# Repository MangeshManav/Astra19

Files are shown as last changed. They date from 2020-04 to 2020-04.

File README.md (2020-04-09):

# Astra19
Face Shields For Frontliners
* 
Face shield provides protection of the facial area and associated mucous membranes (eyes,
nose, mouth) from splashes, sprays and spatter of body fluids.

A Face Shield is attached to the head with the help of a headband and an elastic strap. The
headband is made from MDF sheets. A transparent clear polyester sheet is used as a shield that
protects the face from any airborne fluid particles. This is secured to the headband as shown in
the photos. Used shields can be removed and replaced with new shields very easily.

During this pandemic of COVID-19, there is an immense shortage of Face shields in the market
which is a must have accessory for our frontline warriors including Police & Healthcare
professionals who are exposed to the COVID positive patients day-in and day-out. Due to their
acute shortage, prices have shot up, exposing these frontline warriors at severe risk.

The Face Shield Project is a collaborative effort by Venture Center Team and group of startup entrepreneurs to design, fabricate and deliver faceshields to the frontline workers.

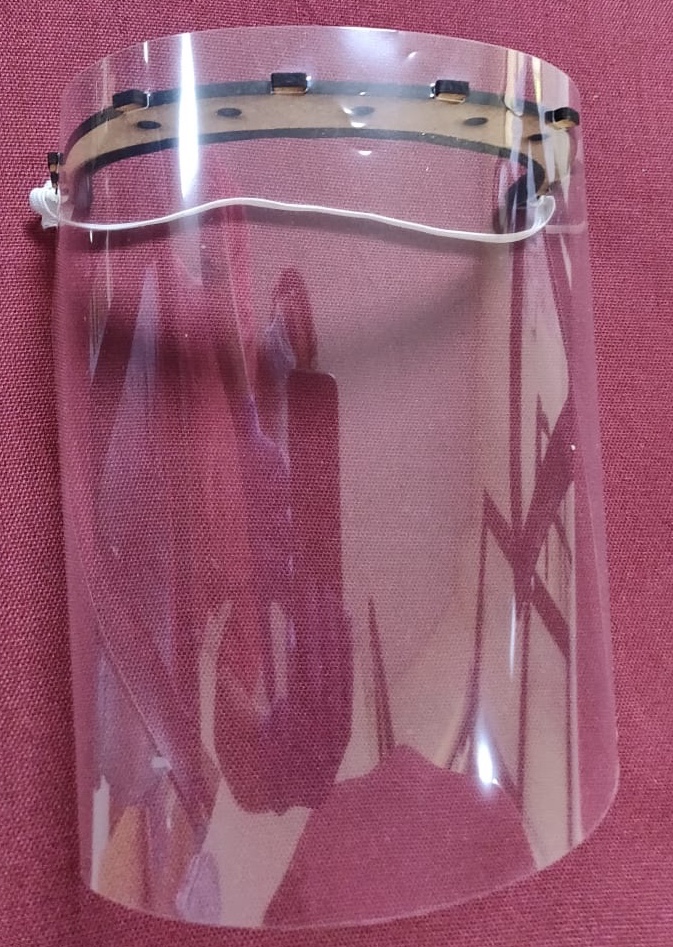
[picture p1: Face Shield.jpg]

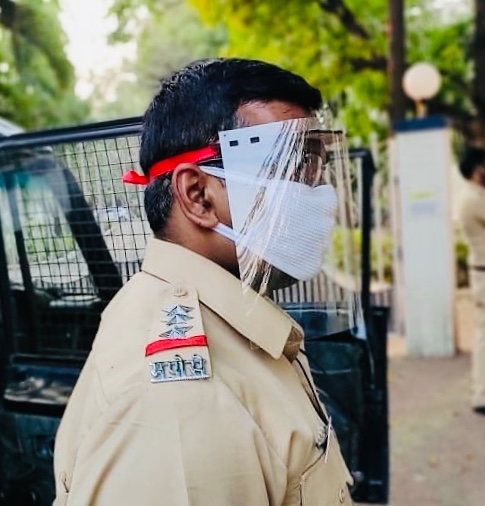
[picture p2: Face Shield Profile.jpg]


Shield: [][cc-by-sa]

This work is licensed under a [Creative Commons Attribution-ShareAlike 4.0
International License][cc-by-sa].

[][cc-by-sa]

[cc-by-sa]: http://creativecommons.org/licenses/by-sa/4.0/
[cc-by-sa-image]: https://licensebuttons.net/l/by-sa/4.0/88x31.png
[cc-by-sa-shield]: https://img.shields.io/badge/License-CC%20BY--SA%204.0-lightgrey.svg

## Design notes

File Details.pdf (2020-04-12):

### Venture Center Startups against COVID-19 Face Shield

Raw Materials
| Material Name | Specifications | Cost for bulk (Rs) | Price per piece (Rs) | Qty required per piece | Source
1 Plastic Sheet or OHP | Sheets | A4, 100 microns + | 190/ packet of 100 pieces | 1.9-2.5 | 1 | Stationary Shop
2 | Headband | MDF Sheet (8*4 sq ft, 3.5 mm) | 320/ Sheet | 1.6 - 3 | 10*15 cm | Plywood Store
3 | Elastic Band | 4-6 mm, | 5/ meter | 1.66 - 3 | 30 cm | Textile/Tailoring Shop
4 | Laser Cutter | Holder and Plastic Sheet cut into shape | 20/Sq Ft | 5 - 10 | 1-2 mins | Wood working/Graphics Store
5 | Miscellaneous Costs | Gloves, Sanitizer, Packaging Bags, Sandpaper, Cleaning Clothes, Tranportation | NA | 6 - 10 | | NA

Design files: https://github.com/MangeshManav/Astra19 or https://tinyurl.com/fspune

Face Shield Details: http://www.protoshop.in/covid19-faceshields/

Contact:

1. 9975571504 (Aditya Kabra)
2. 7798626714 (Mitesh Rasal)

Credits: Inspired from Maker’s Asylum Mumbai

Protected by Creative Commons License:

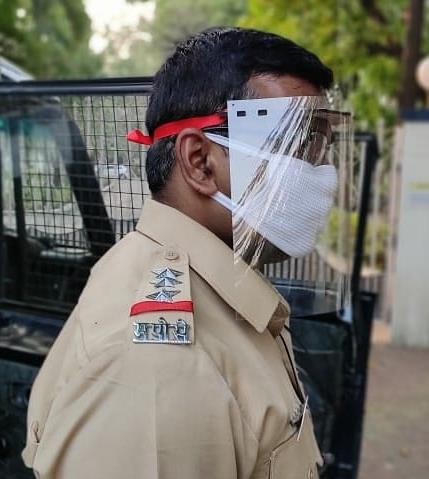
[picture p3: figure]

Subject to the terms and conditions of this Public License, the Licensor hereby grants You a worldwide, royalty-free, non-sub-licensable, non-exclusive, irrevocable license to exercise the Licensed Rights in the Licensed Material to: reproduce and Share the Licensed Material, in whole or in part, for Non-commercial purposes only; and produce, reproduce, and Share Adapted Material for Non-commercial purposes only.

### Face Shield

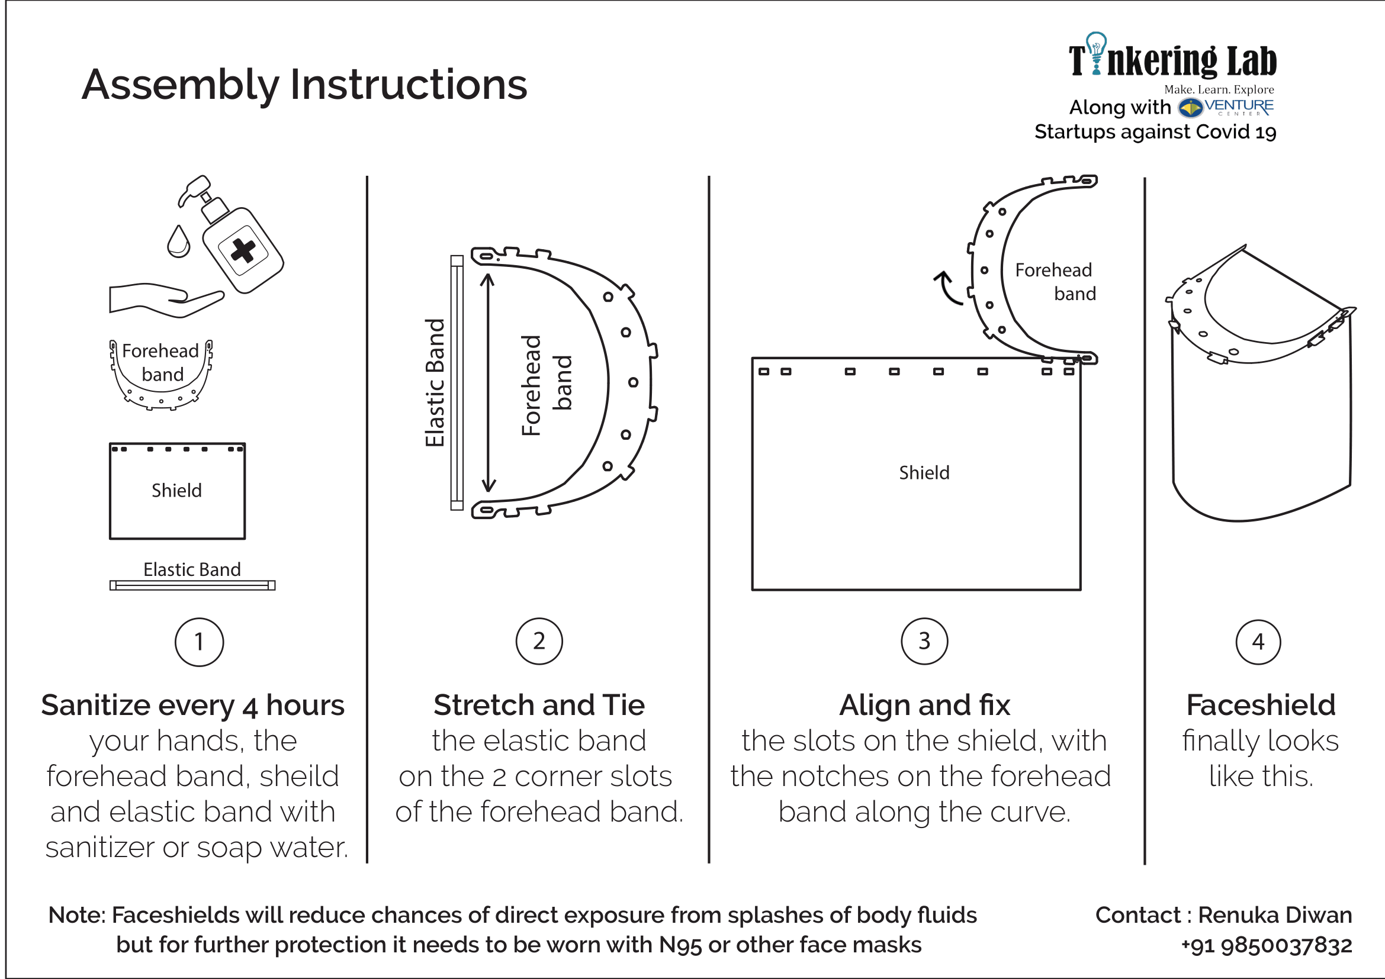
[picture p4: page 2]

### Face Shield

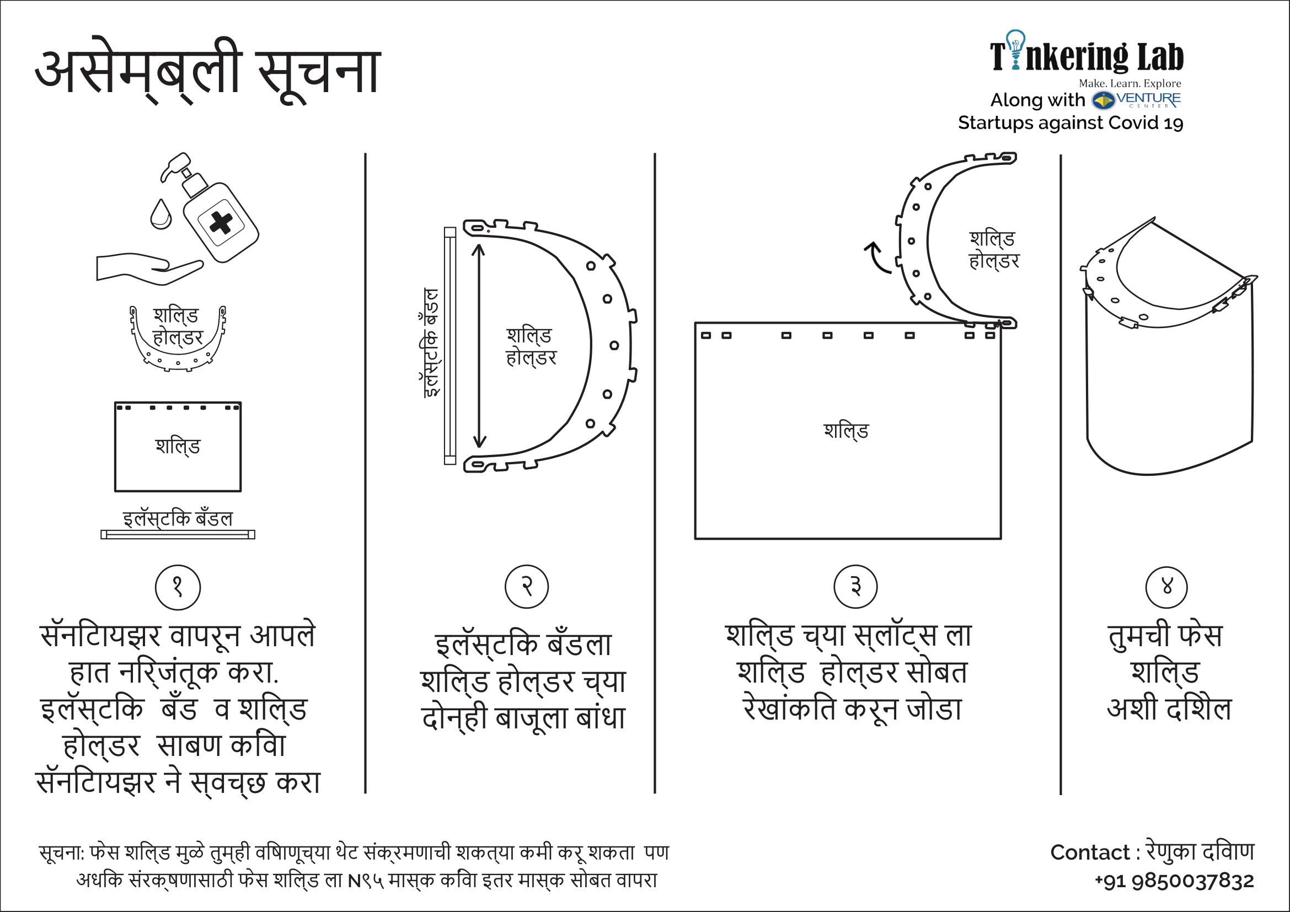
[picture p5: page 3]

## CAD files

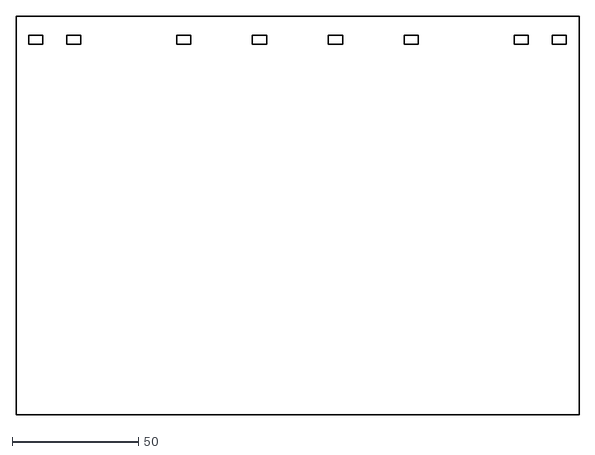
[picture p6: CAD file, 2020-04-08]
Plastic Sheet.dxf
222.8 x 157.5

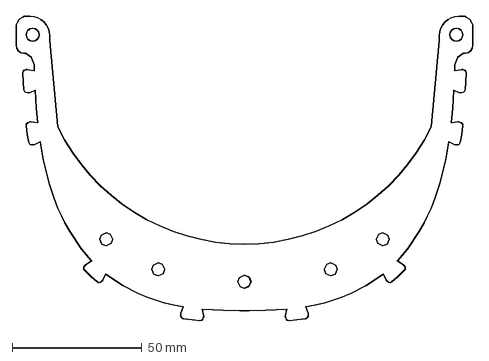
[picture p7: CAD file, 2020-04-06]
Headband.DXF
175.7 x 117.2 mm

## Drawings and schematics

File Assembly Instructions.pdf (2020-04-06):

## Assembly Instructions

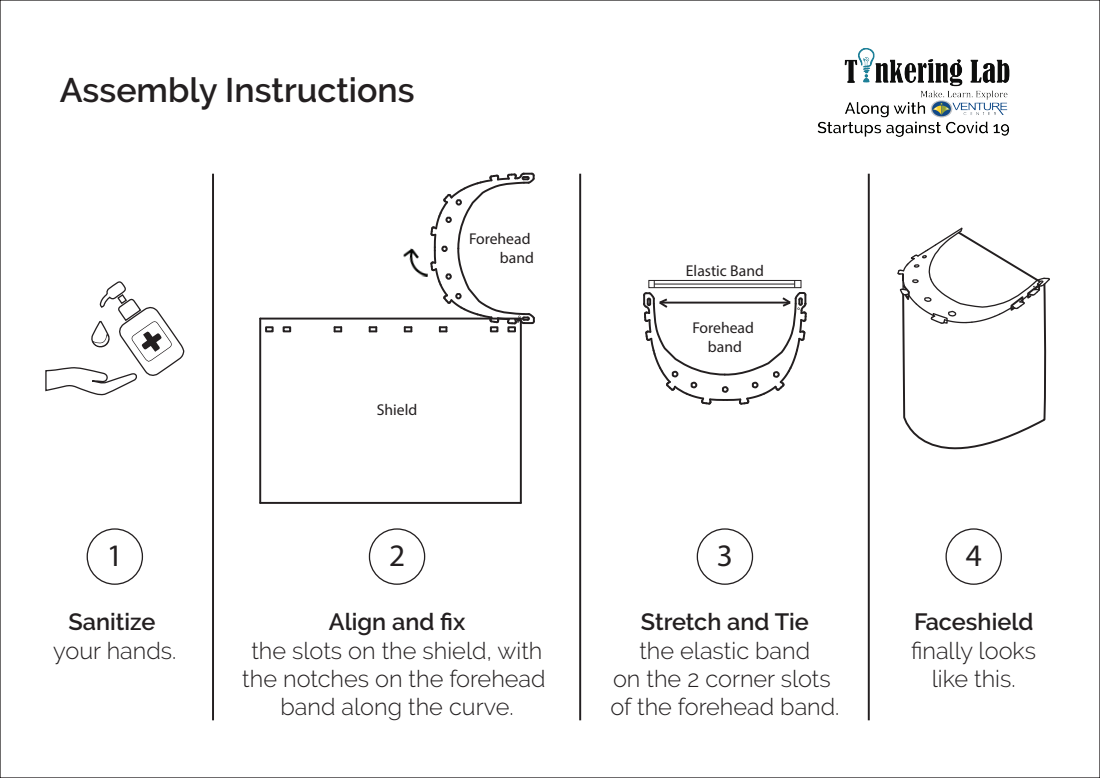
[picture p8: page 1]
Sanitize your hands.; Shield; Forehead band; Elastic Band; Faceshield finally looks like this.

Align and fix
the slots on the shield, with
the notches on the forehead
band along the curve.

Stretch and Tie
the elastic band
on the 2 corner slots
of the forehead band.

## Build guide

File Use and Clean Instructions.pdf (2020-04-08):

## Face Shields

Instructions for use:

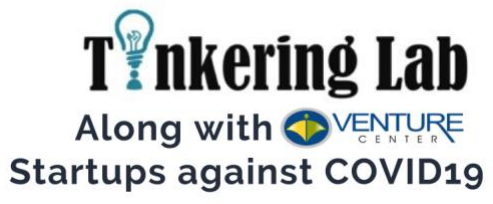
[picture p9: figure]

1. Do not touch the transparent sheet while wearing it.
2. The transparent sheets can be replaced as per the need.
3. Replace the Face Shield as soon as there is a splatter of bodily fluids on the sheet & dispose of the Face Shield properly.
4. Replace transparent sheets every day. The headband can be reused after proper sterlization.
5. Disinfection needs to be carried out every day. Follow the disinfection protocol

Disinfection protocol for End user: Soap/ Alcohol based sanitizers

Your face shield has 2 components
a) A Reusable headband with elastic (b) A transparent sheet attached to the reusable headband.

While Using soap
1. Take a clean cloth and dip it in a soapy water.
2. Rub the headband (both sides along with the elastic) thoroughly with the cloth and allow the soap to remain on the surface for 30 seconds.
3. Wipe the soap foam from the headband with another clean cloth
4. Allow to dry before using again

While Alcohol based cleaning

1. Use a 70% isopropyl alcohol wipe to rub the surface of the headband on both the sides and in gaps and crevices. Also rub along the elastic band with the same or a new alcohol wipe.
2. In case wipes are not available use a tissue paper. Put a coin size drop of gel-based hand sanitizers (61-70% alcohol content) on the top surface of headband. Wipe it with a clean tissue paper. Repeat the same procedure for the other side of the headband and the elastic.

In case of problems:

Call – Sayali: +91-8788554002

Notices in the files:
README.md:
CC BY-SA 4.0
